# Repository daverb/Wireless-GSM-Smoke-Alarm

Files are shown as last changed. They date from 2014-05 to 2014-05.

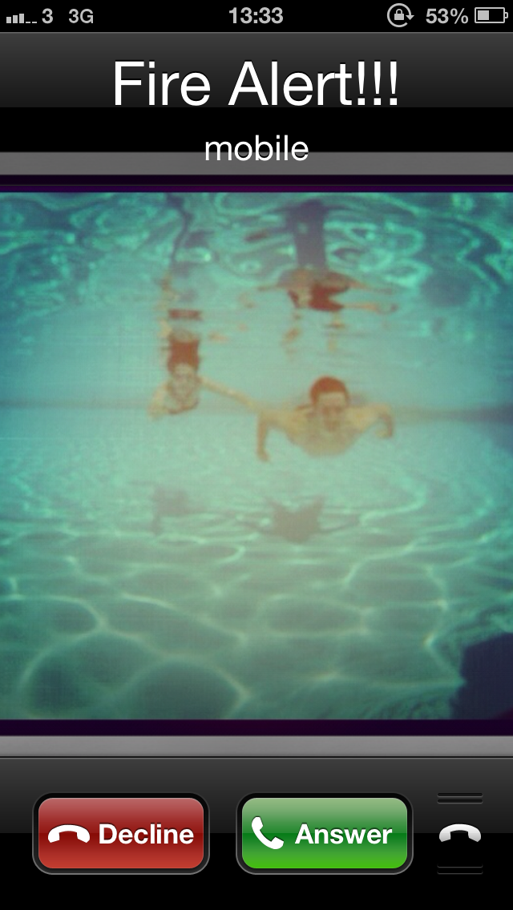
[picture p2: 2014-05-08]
Images/Photo 25-03-2013 13 33 07.png

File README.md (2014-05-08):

Wireless GSM Smoke Alarm - Final Year Engineering Project
========================

###Overview:
This repository contains the Arduino code used in my Final Year B. Eng Electronic Engineering Project.

This project utilised two Arduino boards, a Siemens TC35i GSM module, a smoke detector, and a RF transmitter/receiver pair to create a wireless smoke detection system that can make a phone call to alert a home owner to a fire in their property. The primary purpose of this was to provide an additional tactile warning to people who may be deaf or hard of hearing.

### Technical Guide

For all technical details, please see the document: 'DavidBursonFYPReport.pdf'

This is the final submitted report for my project and includes all technical explanations, wiring diagrams and code.

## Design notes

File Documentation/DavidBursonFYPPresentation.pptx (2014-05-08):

## Tactile Smoke-Detector Interface

David Burson
Supervised by Dr Barry McMullin
B. Eng Electronic Engineering 2013

## Project Brief

- Fires are an added danger to people who are deaf/hard of hearing as they may fail to hear a smoke detector.
- Design a solution that will provide a mobile, tactile danger warning to a user in the case of a smoke detection.

Tactile Smoke-Detector Interface

## Breakdown of Problems

- Method of sensing a danger?
  - Investigate common smoke detection methods.
  - Choose one.
- How to process danger?
  - How to handle multiple detection points?
- How to communicate danger to user?
  - Develop portable device or adapt existing?
  - How to handle multiple detectors in a location?

Tactile Smoke-Detector Interface

## Problem Solving

Tactile Smoke-Detector Interface

- Method of sensing a danger
  - The most common household fire detection method is a ceiling mounted smoke-detector.
  - Operate in two ways; Ionization or Photoelectric
  - Smoke Detectors’ IC can be adapted using designated
I/O Pin to interface with a microcontroller.

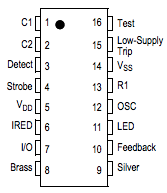
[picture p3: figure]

## Problem Solving

Tactile Smoke-Detector Interface

- How to Process Danger
  - Select a microcontroller
  - PIC or Arduino?
  - Arduino UNO, compact & practical for early prototyping
  - Multiple Analog, Digital and Power I/O Pins
  - Serial Interface

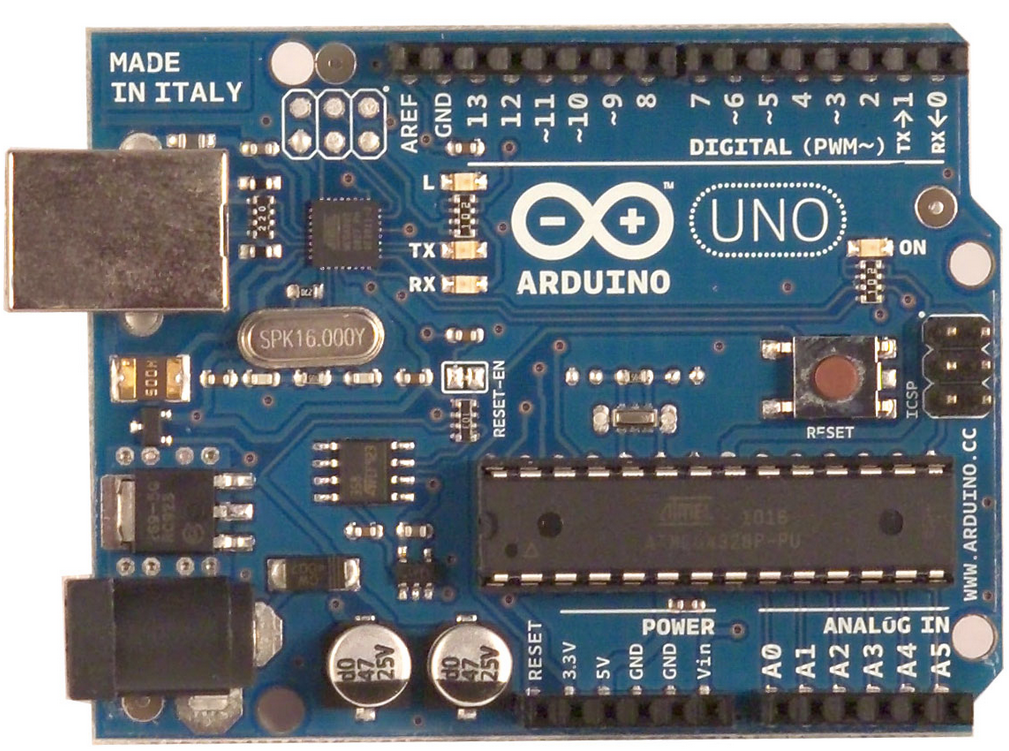
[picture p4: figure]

## Problem Solving

Tactile Smoke-Detector Interface

- How to Communicate Danger?
  - How to handle multiple detectors in a home
    - 433 MHz RF Transmitter interfaced with microcontroller on each smoke-detector.
    - RF Receiver at central ‘server’ receives signal and processed by microcontroller.

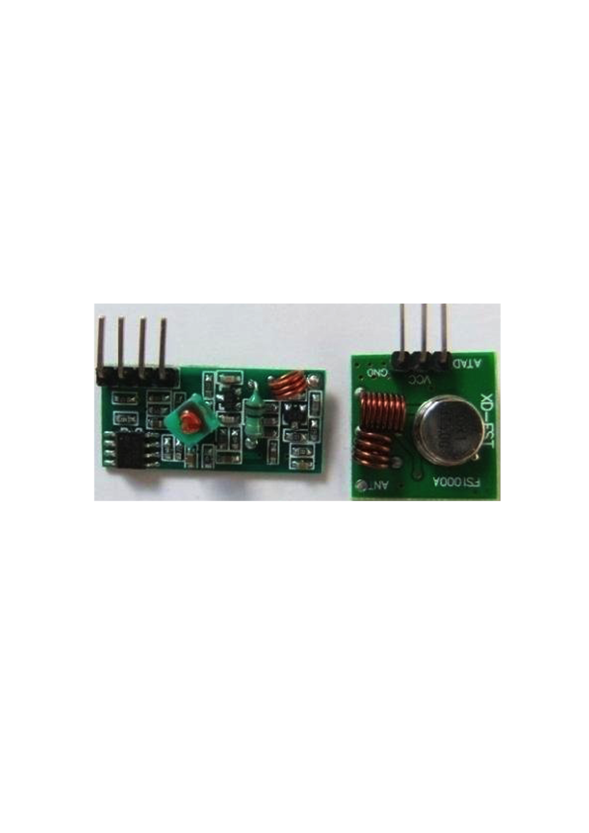
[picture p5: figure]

## Problem Solving

Tactile Smoke-Detector Interface

- How to Alert Hearing-Impaired User?
  - Mobile alert method
    - A mobile phone is a ready-made portable device, danger alert can be achieved by sending a warning call or SMS.
    - Incorporate a GSM module into the receiver circuit in order to transmit calls or SMS’.
    - Chose the SIEMENS TC35 GSM Module Development Board.

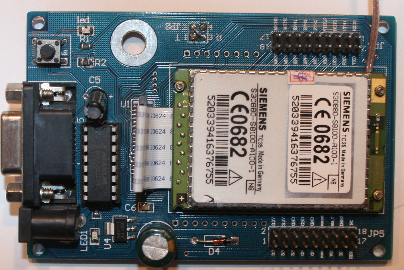
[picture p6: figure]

## Problem Solving

Tactile Smoke-Detector Interface

- How to Alert Sleeping User?
  - Under pillow vibrator.
  - When warning signal is received, vibration motor pulses in plastic encasement to wake sleeping user.
  - If user chooses to keep phone by bedside, provides two alternating vibrating alerts.

## Progress

Tactile Smoke-Detector Interface

- Smoke-Detection/Transmitter Circuit
  - I/0 pin sends analog voltage signal to microcontroller when activated.
  - Program detects high input, transmits RF signal.
  - Test Push Button.
  - Battery Powered.

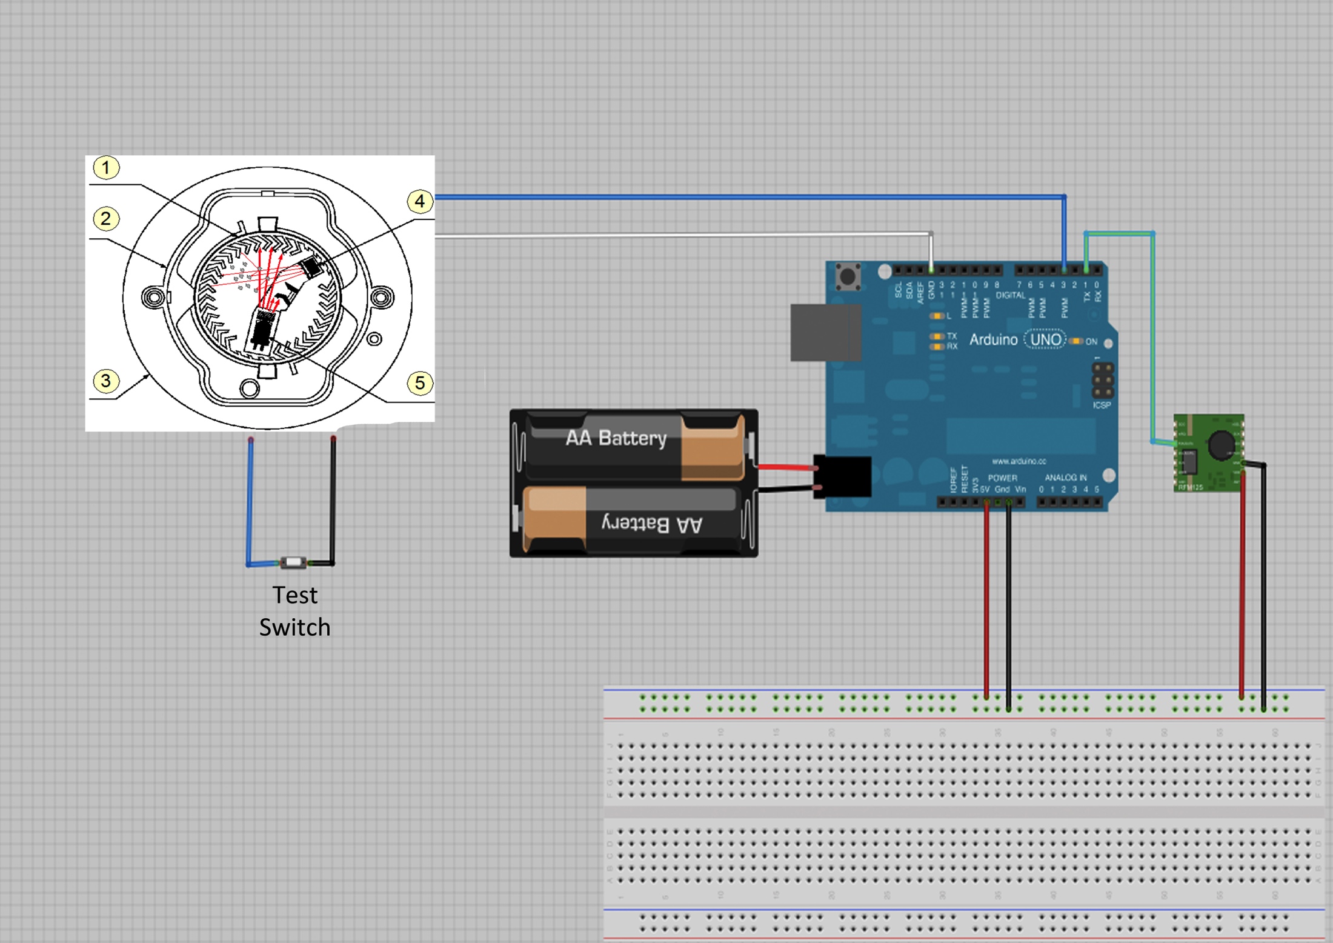
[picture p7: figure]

## Progress

Tactile Smoke-Detector Interface

- Receiver/Warning Circuit
  - RF Receiver collects signal.
  - Signal processed by microcontroller.
  - Program sends AT commands to GSM module in order to transmit warning call or SMS.

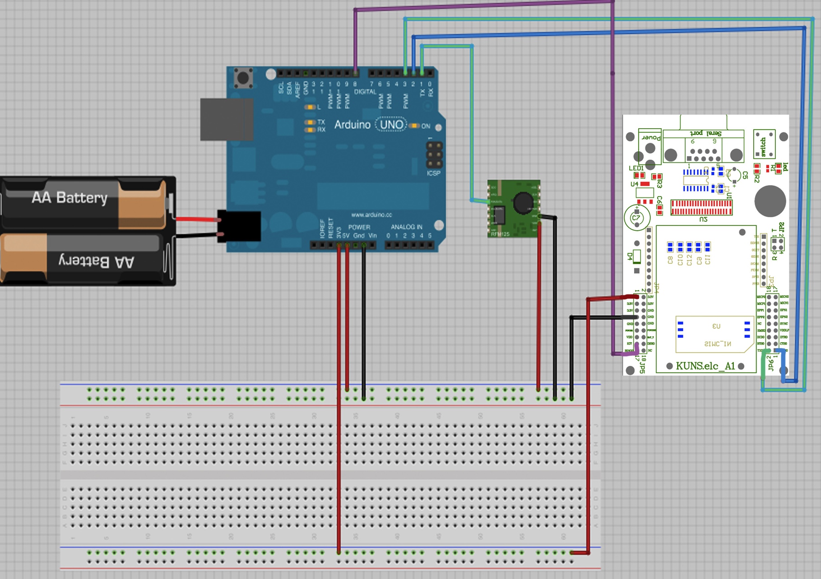
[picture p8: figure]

## To Do

Tactile Smoke-Detector Interface

- Develop code in order to remotely program the call-out number via SMS
  - Proving difficult due to serial connection between TC35 and GSM Module.
- Develop suitable and safe under-pillow vibrator.
- Package project in user-friendly and aesthetically suitable way.

## Conclusion

- Smoke detectors with a small and inexpensive pairing of a RF transmitter and microcontroller transmit a warning
- Received via RF Receiver, processed by controller
- Warning phone call is made via the GSM module to users mobile phone
- Pillow shaker/vibrator is switched on in a pulse loop to wake a sleeping individual
- I now invite questions from the audience.

Tactile Smoke-Detector Interface

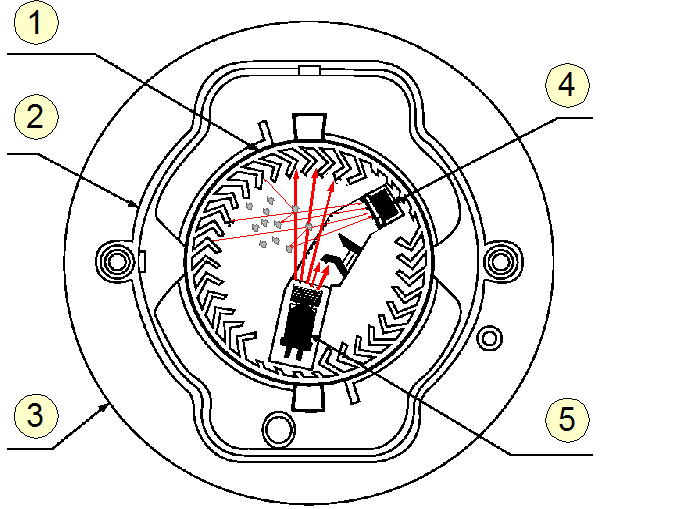
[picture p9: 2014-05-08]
Images/Smokealarm.png

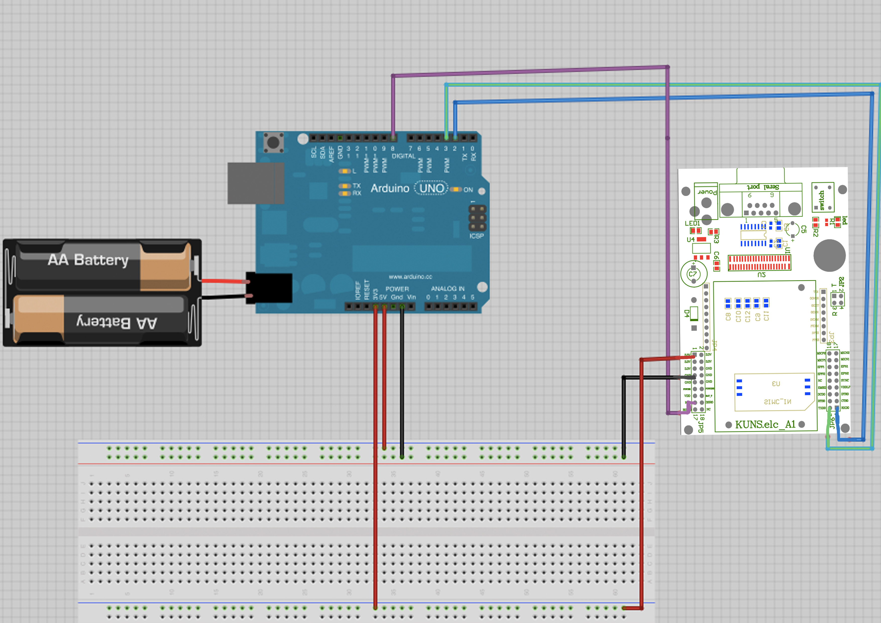
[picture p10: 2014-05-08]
Images/TC35CIRCUIT.jpg

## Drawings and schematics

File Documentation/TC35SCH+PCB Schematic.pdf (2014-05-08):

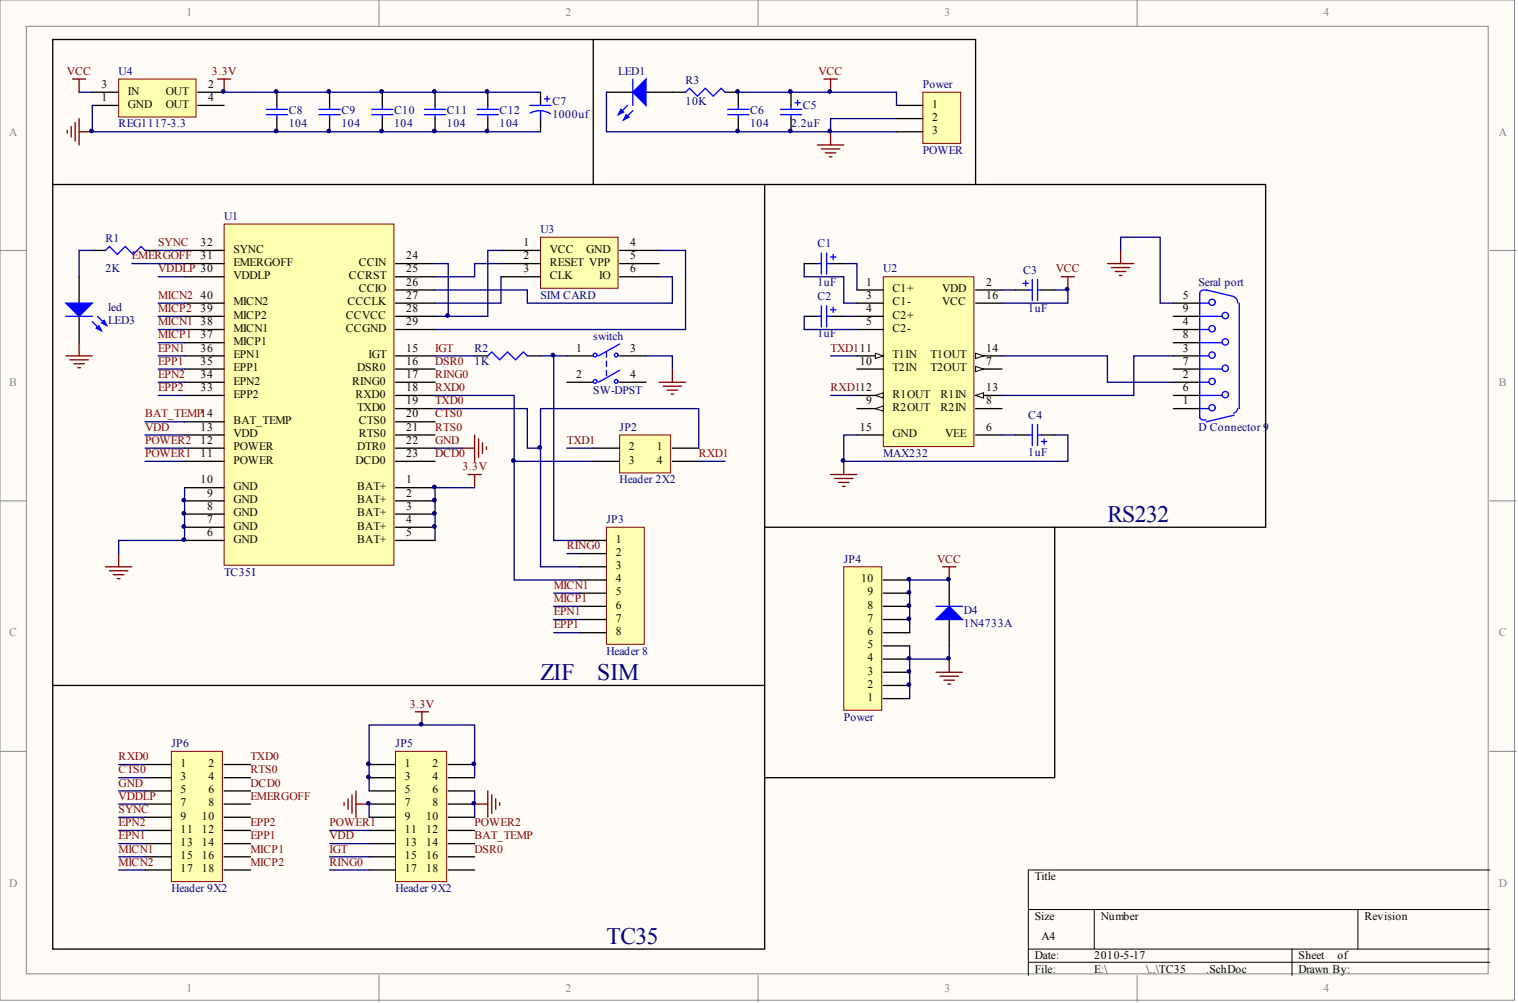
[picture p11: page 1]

switch IGT R2 1 3 | TXD1 | T2IN 10 T1IN 11

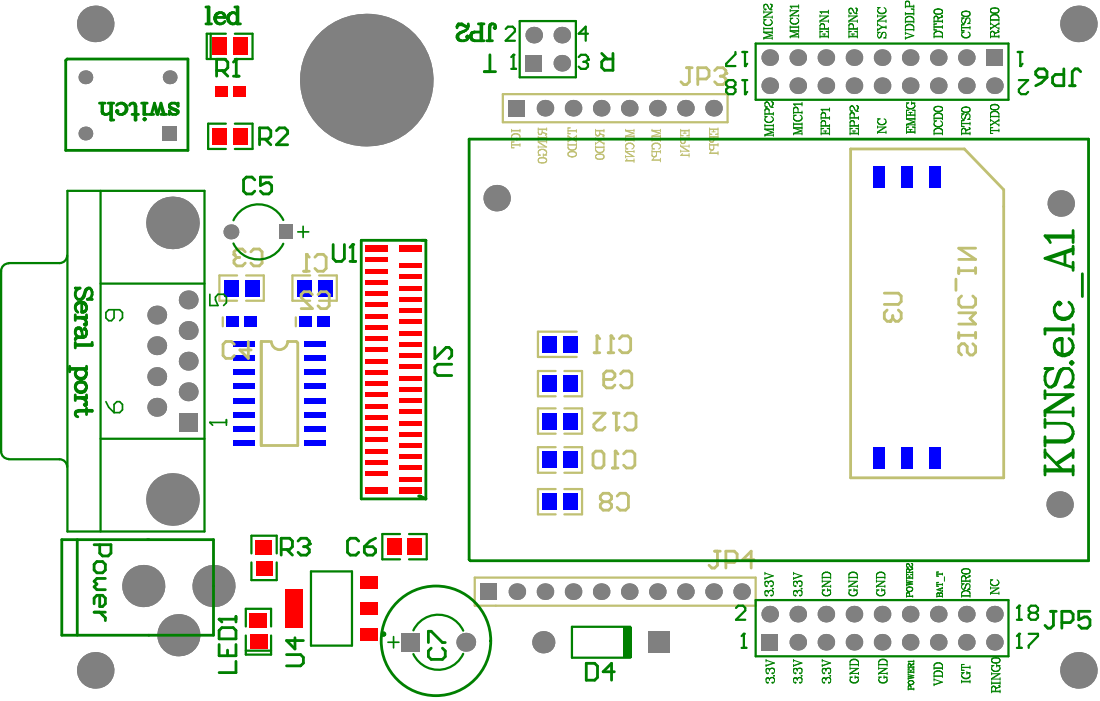
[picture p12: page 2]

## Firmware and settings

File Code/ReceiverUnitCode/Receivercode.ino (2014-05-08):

#include <EEPROM.h>

#include <SoftwareSerial.h>
SoftwareSerial gsmSerial(2,3);
 
char gsm_char,gsm_char_send, data[256], ph_number[13];//="+353879149715";
int x;

#define LED_PIN 13
#define vibratePin 5

void setup()
{
  pinMode(LED_PIN, OUTPUT); 
  pinMode(vibratePin, OUTPUT);
  Serial.begin(1200);  // Hardware supports up to 2400, but 1200 gives longer range
  
  gsmSerial.begin(1200);
  
  if(EEPROM.read(0)!=255){
 for(int y=0; y<13; y++){
   ph_number[y] = EEPROM.read(y);
 }
 Serial.println("\rThe emergency contact number is: \r");
 Serial.println(ph_number);
 }
 
   gsmSerial.print("AT+CMGF=1 \r"); // Setting GSM Module to message mode
   delay(600);

  Serial.begin(1200);  // Hardware supports up to 2400, but 1200 gives longer range
  gsmSerial.begin(1200);
  
   //--- turn on TC35 ---
  // wire pin 8 Arduino to IGT pin on TC35
  // it grounds IGN pin for 100 ms
  // this is the same as pressing the button
  // on the TC35 to start it up

  pinMode(8, INPUT);
  digitalWrite(8, LOW);
  pinMode(8, OUTPUT);
  delay(100);
  pinMode(8, INPUT);
  
  delay(1000);  
  
  // Checking for any new messages containing a set command to reset emergency number
  for(int i=0;i<3;i++){
  checkMessage();
  resetSMS();
 delay(500); 
  }
  
}

void loop()
{
  boolean light_led = false;

  if (readUInt(true) == 288) // Check to see if we got the 88 test number
  {
    light_led = true;
      Serial.println('Received');             // debug value

//  }
  
//  if (light_led)
//  {
      digitalWrite(LED_PIN, HIGH);
    
     gsmSerial.write("ATD+353879149715;\r"); //code to call phone
     digitalWrite(vibratePin, HIGH);
     delay(2000);
     digitalWrite(vibratePin, LOW);
     delay(8500); //11 second delay as takes about 5 seconds to connect call
     gsmSerial.print("ATH0;\r"); //kill call
     
     digitalWrite(LED_PIN, LOW);

  }
}

void delete_All_SMS(){
  for(int i = 1; i <= 10; i++) {
    gsmSerial.print("AT+CMGD=");
    gsmSerial.println(i);
    Serial.print("deleting SMS ");
    Serial.println(i);
    delay(500);
  }

}
  
void sendSMS(){
 
  gsmSerial.print("AT+CMGF=1\r");
  delay(1000);
 gsmSerial.println("AT+CMGS=\"+353879149715\""); //AT command to send SMS
 delay(500); //the length of this delay is very important. 400 is too low
 gsmSerial.print("Hello World"); //Print the message
 delay(100);
 gsmSerial.println((char)26);
  Serial.println("\r\nSMS Sent\r\n");

}

void checkMessage() {
  
  gsmSerial.println("AT+CMGR=1 \r");    //Reads the first SMS
         
        for (x=0;x < 255;x++){            
            data[x]='\0';                        
        } 
        x=0;
        do{
            while(gsmSerial.available()==0);
            data[x]=gsmSerial.read();  
            x++;           
            //if(data[x-1]==0x0D&&data[x-2]=='"'){
                //x=0;
           // }
        }while(!(data[x-1]=='K'&&data[x-2]=='O'));

        data[x-3]='\0';        //finish the string before the OK
        
        delay(1000); //delay so as CMGR command returns a value before printing data

        Serial.println("\r\nMessage contains: \r");
        Serial.println(data);    //shows the message  
  
}

void resetSMS() {
  boolean contains = false;
  for (x = 0; x<strlen(data); x++) {
    if (data[x]=='S'&&data[x+1]=='e'&&data[x+2]=='t'){
      contains = true;
      break;
        }
        else {
            contains = false;
        }   
    }
  if (contains == true){
        Serial.println("This SMS contains the word; 'Set'. \r");
        for (x = 0; x<strlen(data); x++) {
        if (data[x]=='+'&&data[x+1]=='3'&&data[x+2]=='5'){  //finds characters beginning with +35 and then saves the number
          for(int i=0;i<13;i++){
            ph_number[i]=data[x];
            EEPROM.write(i, data[x]);
            
            x++;
          }
          Serial.println("This message was sent from: ");
          Serial.println(ph_number); Serial.println("\rThis is the new emergency call number.\r");
          delete_All_SMS();
          }
        }
  }
  else{
    Serial.println("There is no set message at this time. \r");
  } 
       
}

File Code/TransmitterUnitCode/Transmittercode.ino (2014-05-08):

//Transmitter Code
//David Burson FYP

int analogPin = A0;
int x = 0;
int ledPin = 13;                 // LED connected to digital pin 13

void setup()
{
  pinMode(analogPin, INPUT);
  pinMode(ledPin, INPUT);
  pinMode(ledPin, OUTPUT);
  digitalWrite(ledPin, LOW);

  Serial.begin(1200);  // Hardware supports up to 2400, but 1200 gives longer range
}

void loop()
{
  x = analogRead(analogPin);    // read the input pin
  float voltage = x * (5.0 / 1023.0);
  
  if (voltage>3) {
    Serial.println(voltage);             // debug value
    Serial.println("\r\n");
    
    writeUInt(288); // Put any number you want to send here (71 is just a test)
    
   digitalWrite(ledPin, HIGH);   // sets the LED on
    delay(1000);                  // waits for a second
    digitalWrite(ledPin, LOW);    // sets the LED off
    delay(10000); 
  }
}
